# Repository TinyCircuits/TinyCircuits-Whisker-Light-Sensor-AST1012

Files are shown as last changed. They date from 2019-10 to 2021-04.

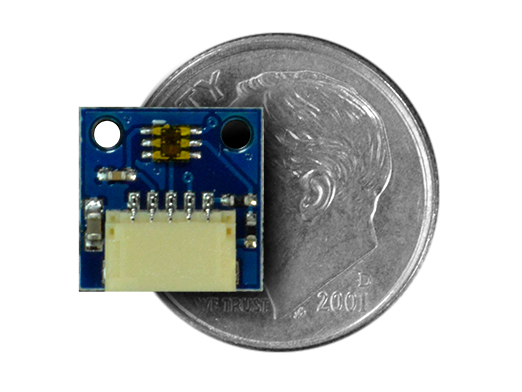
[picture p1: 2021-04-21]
images/AST1012-Product-Photo-03.png

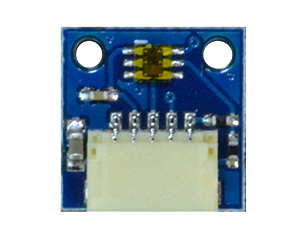
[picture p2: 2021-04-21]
images/AST1012-Learn-Photo-01.png

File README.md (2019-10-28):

# TinyCircuits Wireling Light Sensor
# AST1012 Rev2

The design files are located under design_files/ for the TinyCircuits AST1012 Rev 2 PCB. This is a Wireling board which features the AMS TSL2572 ambient light sensor with built in UV rejection filter and is also capable of operating in IR light environments. Its high sensitivity range enables it to operate even behind dark glass (such as in portable applications like Smartphones).

Format is in Cadsoft Eagle format - Eagle version 6.2 was used for the original design.

For more infomation on this, check out the product page at TinyCircuits.com

# License:

Design by TinyCircuits.
All design files are released under the Creative Commons Attribution Share-Alike 3.0 License, see the following link for details: http://creativecommons.org/licenses/by-sa/3.0

All text above must be included in any redistribution or derived design

This project uses designs and concepts developed as part of the Arduino project and the LilyPad project.  The TinyCircuits design files themselves (schematics, PCB and libraries) are not directly derived from these works' design files and have been created new, however the concepts and basic architecture behind the TinyDuino and TinyLily products are derived and we thank the hard work of the organizations below for their contributions to open-source hardware:
  
Original Arduino Uno Design by Team Arduino

LilyPad Arduino Design by Leah Buechley and Sparkfun Electronics

Please support the open-source hardware community

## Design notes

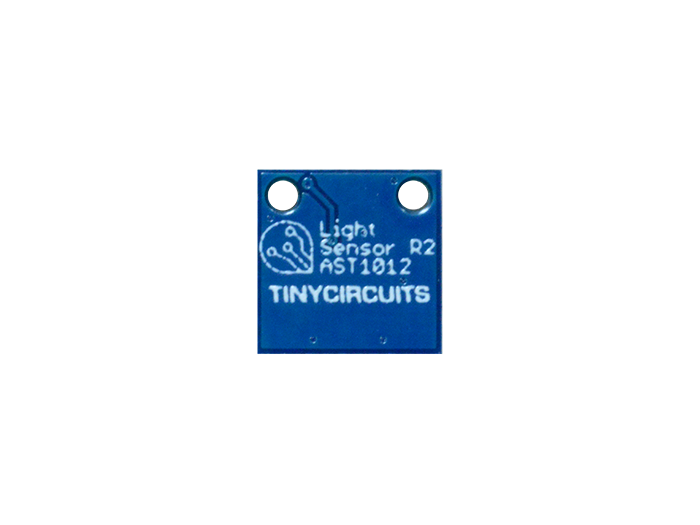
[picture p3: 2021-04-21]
images/AST1012-Product-Photo-02.png

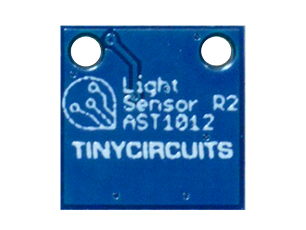
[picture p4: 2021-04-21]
images/AST1012-Learn-Photo-02.png

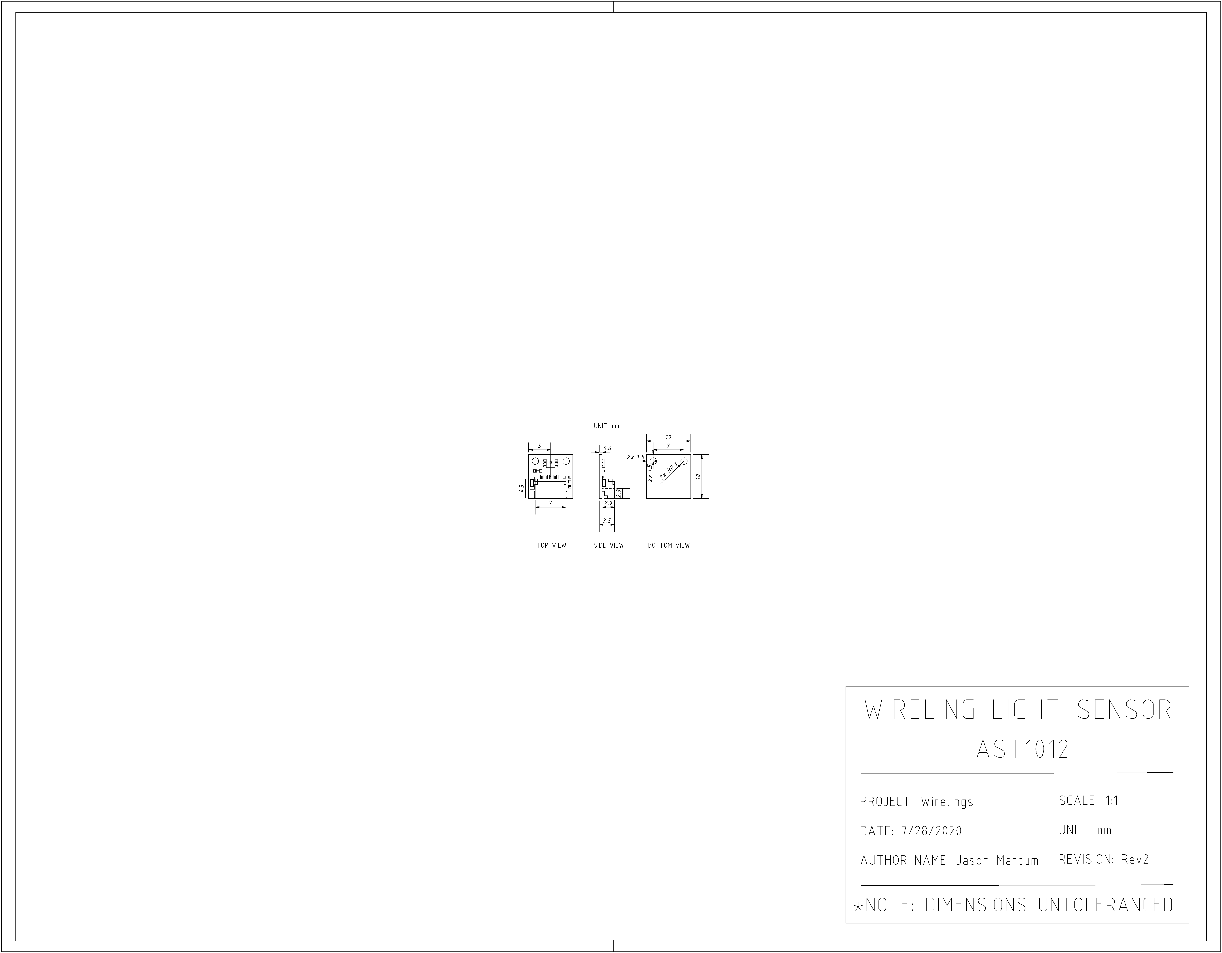
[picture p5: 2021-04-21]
cad/Wireling_LIGHTSENSOR_AST1012_REV2-DETAILED_DRAWING-PNG.png

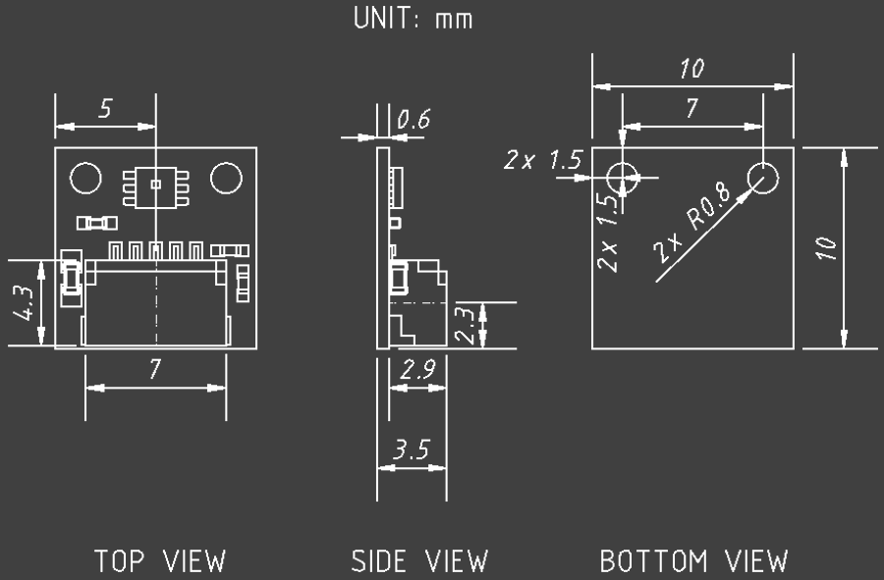
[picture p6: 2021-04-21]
cad/Wireling_LIGHTSENSOR_AST1012_REV2-DETAILED_DRAWING_COMPACT-PNG.png

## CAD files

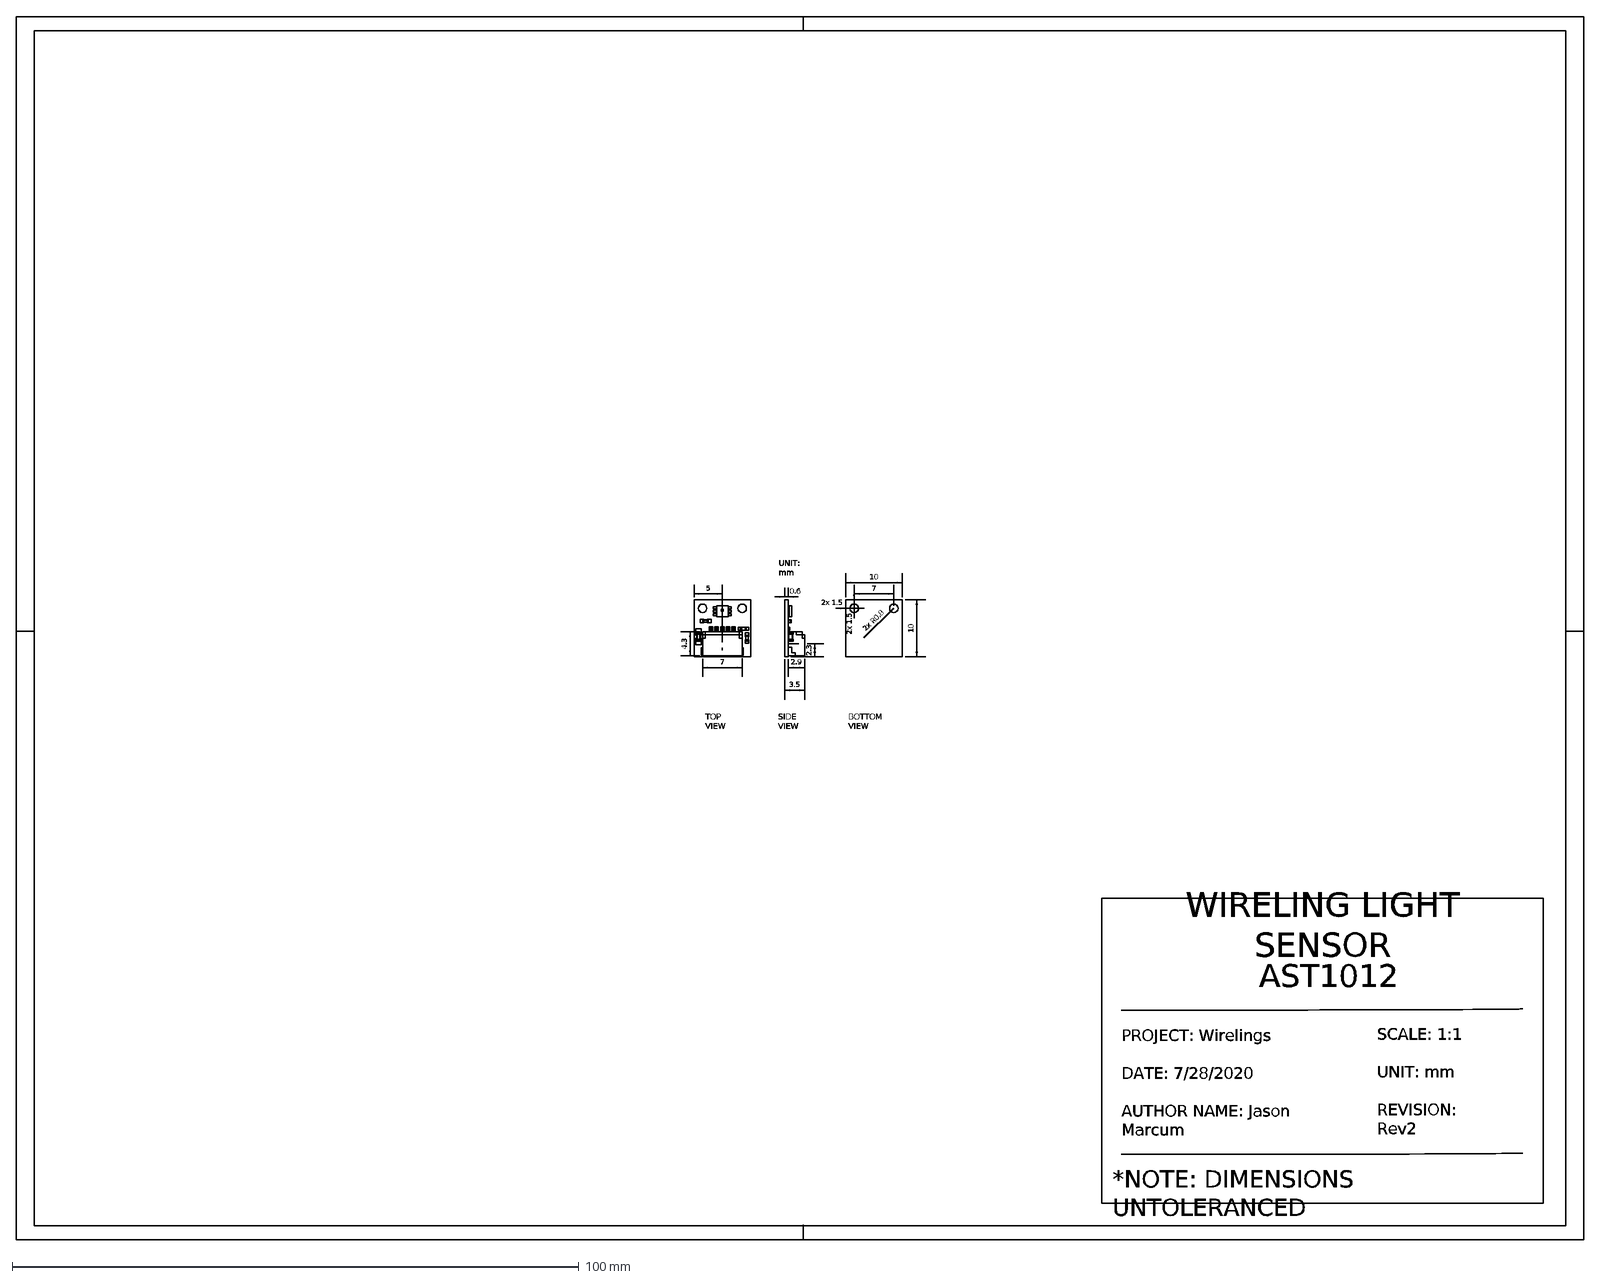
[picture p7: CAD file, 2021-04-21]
cad/Wireling_LIGHTSENSOR_AST1012_REV2-DETAILED_DRAWING-DXF.dxf
*NOTE: DIMENSIONS UNTOLERANCED
UNIT: mm
5
7
4.3
2.3
2.9
3.5
0.6
10
2x 1.5
2x R0.8
TOP VIEW
BOTTOM VIEW
SIDE VIEW
WIRELING LIGHT SENSOR
AST1012
SCALE: 1:1 UNIT: mm REVISION: Rev2
PROJECT: Wirelings DATE: 7/28/2020 AUTHOR NAME: Jason Marcum

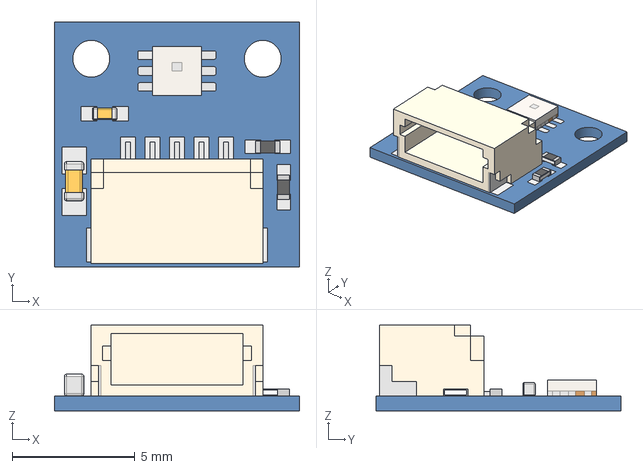
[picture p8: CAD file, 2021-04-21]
cad/Wireling_LIGHTSENSOR_AST1012_REV2-STEP.step
10.0 x 10.0 x 3.50 mm

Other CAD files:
cad/Wireling_LIGHTSENSOR_AST1012_REV2-IGES.iges
cad/Wireling_LIGHTSENSOR_AST1012_REV2-STL.stl

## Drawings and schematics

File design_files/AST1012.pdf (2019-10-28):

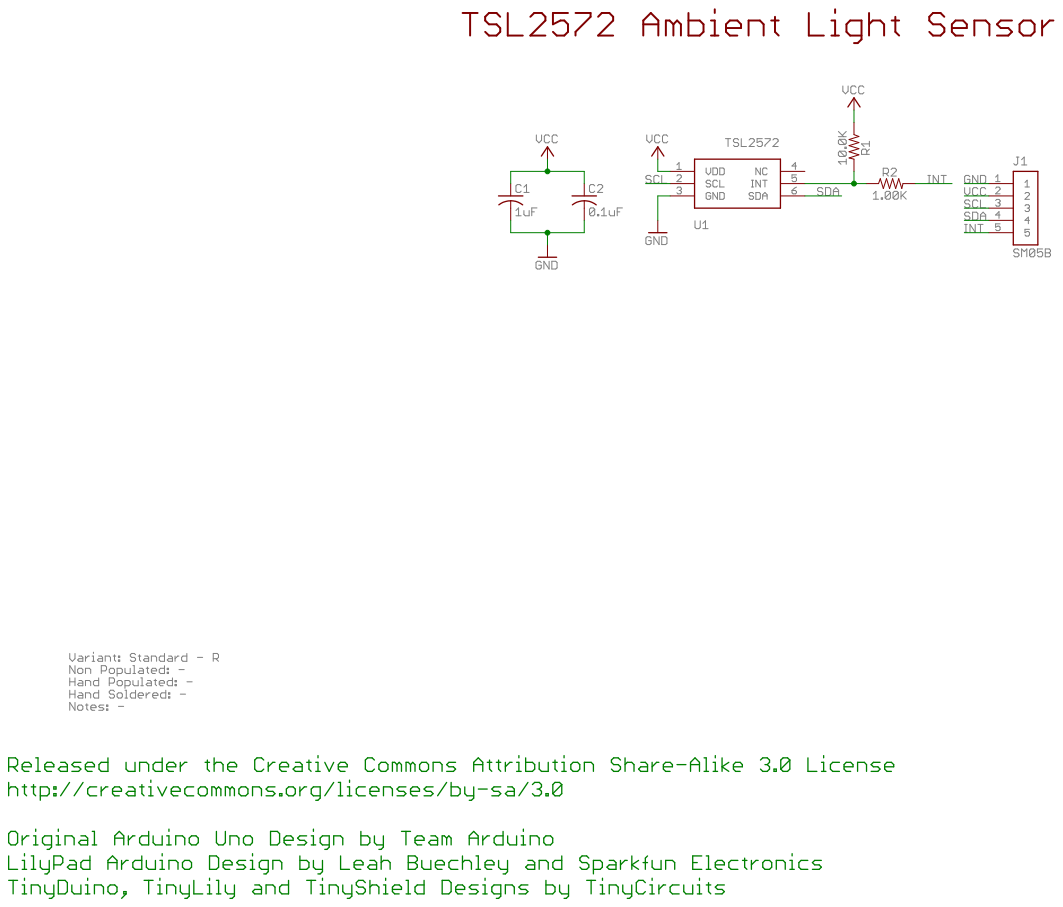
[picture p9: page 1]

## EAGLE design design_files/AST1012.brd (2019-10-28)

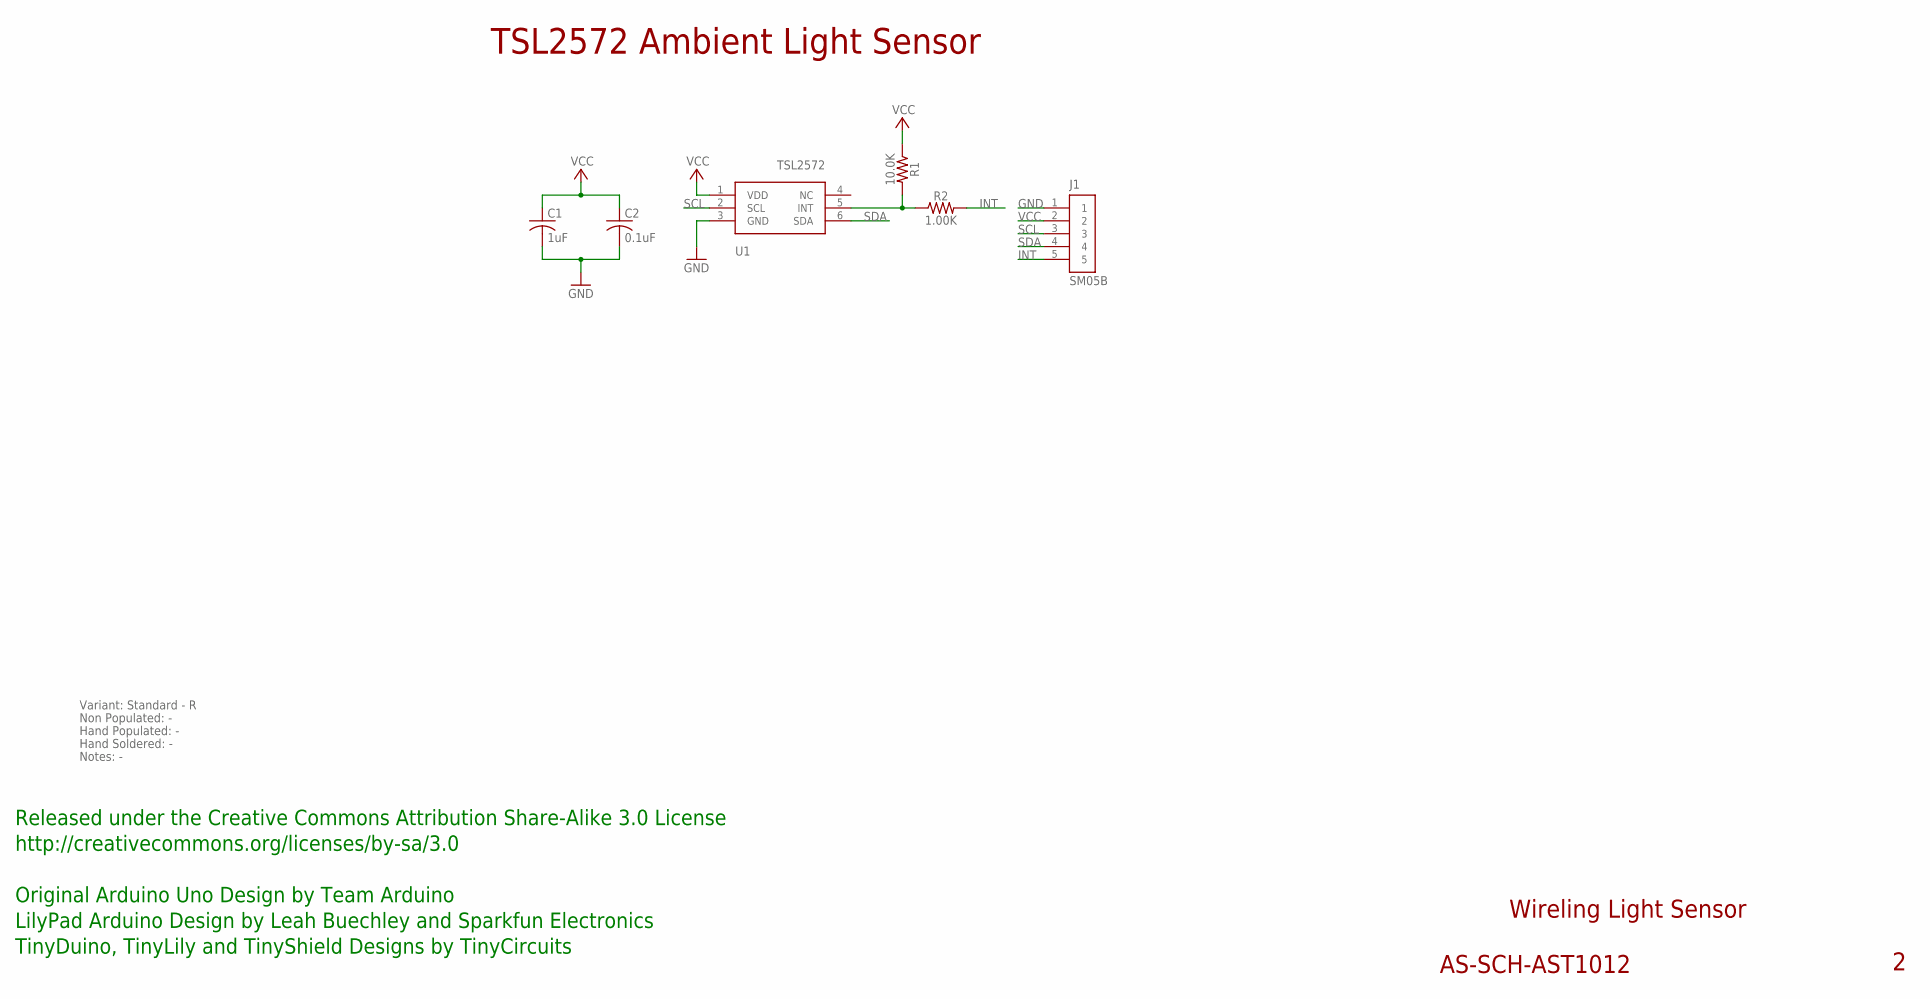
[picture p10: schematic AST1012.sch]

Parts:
C1: 1uF; C0603; PARTNO AS-ITM-00410
C2: 0.1uF; C0402
J1: SM05B; JST_SH_5X1_EDGE
R1: 10.0K; 0402; PARTNO AS-ITM-00032
R2: 1.00K; 0402; PARTNO AS-ITM-00003
U1: TSL2572; PARTNO AS-ITM-00116

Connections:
GND: C1.2, C2.2, J1.1, U1.3 (GND)
GPIO1: R1.2, R2.1, U1.5 (INT)
INT: J1.5, R2.2
SCL: J1.3, U1.2 (SCL)
SDA: J1.4, U1.6 (SDA)
VCC: C1.1, C2.1, J1.2, R1.1, U1.1 (VDD)

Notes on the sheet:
Wireling Light Sensor
AS-SCH-AST1012
TSL2572 Ambient Light Sensor
Released under the Creative Commons Attribution Share-Alike 3.0 License
http://creativecommons.org/licenses/by-sa/3.0
Original Arduino Uno Design by Team Arduino
TinyDuino, TinyLily and TinyShield Designs by TinyCircuits
LilyPad Arduino Design by Leah Buechley and Sparkfun Electronics
Variant: Standard - R
Non Populated: -
Hand Populated: -
Hand Soldered: -
Notes: -

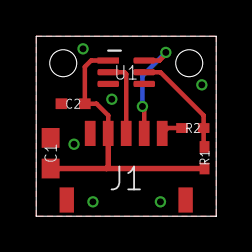
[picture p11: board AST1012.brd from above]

Board: 2 copper layers, 10.0 x 10.0 mm, 7 parts (0 on the bottom side), 6 nets.

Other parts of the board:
U$1: DOCFIELD-TINYCIRCUITS-PCB

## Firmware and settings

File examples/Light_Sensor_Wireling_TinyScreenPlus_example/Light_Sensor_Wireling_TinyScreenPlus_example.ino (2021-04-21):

/*************************************************************************
 * TSL2572 Ambient Light Sensor Wireling Tutorial:
 * This program will print the lux value read from the sensor to both the 
 * TinyScreen+ if used, and the Serial Monitor
 * 
 * Hardware by: TinyCircuits
 * Code by: Laveréna Wienclaw for TinyCircuits
 *
 * Initiated: 11/29/2017 
 * Updated: 04/21/2021
 ************************************************************************/

#include <Wire.h>         // For I2C communication with sensor
#include <TinyScreen.h>   // For interfacing with the TinyScreen+
#include <Wireling.h>     // For interfacing with Wirelings

// TinyScreen+ variables
TinyScreen display = TinyScreen(TinyScreenPlus);
int background = TS_8b_Black;

// Communication address with the sensor
#define TSL2572_I2CADDR     0x39

// Sets the gain
#define   GAIN_1X 0
#define   GAIN_8X 1
#define  GAIN_16X 2
#define GAIN_120X 3

//only use this with 1x and 8x gain settings
#define GAIN_DIVIDE_6 false

// Global variable for gain value used to Read the sensor
int gain_val = 0;

// Make Serial Monitor compatible for all TinyCircuits processors
#if defined(ARDUINO_ARCH_AVR)
  #define SerialMonitorInterface Serial
#elif defined(ARDUINO_ARCH_SAMD)
  #define SerialMonitorInterface SerialUSB
#endif

void setup() {
  SerialMonitorInterface.begin(9600);
  Wire.begin();

  // Initialize Wireling
  Wireling.begin();
  Wireling.selectPort(0); // Port #'s correspond to backside of the Adapter TinyShield

  // Setup and style for TinyScreen+
  display.begin();
  display.setFlip(true);
  display.setBrightness(15);
  display.setFont(thinPixel7_10ptFontInfo);
  display.fontColor(TS_8b_White, background);

//***************************************
// SETTINGS & ADJUSTMENTS 
//***************************************
//  TSL2572Init(GAIN_1X);
//  TSL2572Init(GAIN_8X);
  TSL2572Init(GAIN_16X);
  //TSL2572Init(GAIN_120X);
}

void loop() {
  float AmbientLightLux = Tsl2572ReadAmbientLight();

  // Print lux value to Serial Monitor
  SerialMonitorInterface.print("Lux: ");
  SerialMonitorInterface.println(AmbientLightLux);

  // This will make the screen look a little unsteady but is needed in order
  // to clear old values 
  display.clearScreen();
  printScreen(AmbientLightLux); // Print lux to TinyScreen
  delay(500);
}

// Prints the lux values to the TinyScreen
void printScreen(float luxValue){
  // This will make the screen look a little unsteady but is needed in order
  // to clear old values 
  display.clearScreen();
  
  display.fontColor(TS_8b_White, background);
  display.setCursor(0, 0);
  display.print("TSL2572 Values:");

  display.fontColor(TS_8b_Yellow, background);
  display.setCursor(0, 12);
  display.print("Lux = ");
  display.print(luxValue);
}

// Used to interface with the sensor by writing to its registers directly 
void Tsl2572RegisterWrite(byte regAddr, byte regData) {
  Wire.beginTransmission(TSL2572_I2CADDR);
  Wire.write(0x80 | regAddr);
  Wire.write(regData);
  Wire.endTransmission();
}

// Initializes the light sensor to be ready for output
void TSL2572Init(uint8_t gain) {
  Tsl2572RegisterWrite( 0x0F, gain );//set gain
  Tsl2572RegisterWrite( 0x01, 0xED );//51.87 ms
  Tsl2572RegisterWrite( 0x00, 0x03 );//turn on
  if (GAIN_DIVIDE_6)
    Tsl2572RegisterWrite( 0x0D, 0x04 );//scale gain by 0.16
  if (gain == GAIN_1X)gain_val = 1;
  else if (gain == GAIN_8X)gain_val = 8;
  else if (gain == GAIN_16X)gain_val = 16;
  else if (gain == GAIN_120X)gain_val = 120;
}

// Read the lux value from the light sensor so we can print it out
float Tsl2572ReadAmbientLight() {
  uint8_t data[4];
  int c0, c1;
  float lux1, lux2, cpl;

  Wire.beginTransmission(TSL2572_I2CADDR);
  Wire.write(0xA0 | 0x14);
  Wire.endTransmission();
  Wire.requestFrom(TSL2572_I2CADDR, 4);
  for (uint8_t i = 0; i < 4; i++)
    data[i] = Wire.read();

  c0 = data[1] << 8 | data[0];
  c1 = data[3] << 8 | data[2];

  //see TSL2572 datasheet: https://www.mouser.com/ds/2/588/TSL2672_Datasheet_EN_v1-255424.pdf
  cpl = 51.87 * (float)gain_val / 60.0;
  if (GAIN_DIVIDE_6) cpl /= 6.0;
  lux1 = ((float)c0 - (1.87 * (float)c1)) / cpl;
  lux2 = ((0.63 * (float)c0) - (float)c1) / cpl;
  cpl = max(lux1, lux2);
  return max(cpl, 0.0);
}

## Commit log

2019-09-26 images and code fix
    [Light_Whisker_example.ino]
2019-10-28 name change
    [AST1012.brd, AST1012.sch]
2019-11-22 power pin
2020-08-14 Add CAD data
    [Wireling_LIGHTSENSOR_AST1012_REV2-DETAILED_DRAWING-DXF.dxf, Wireling_LIGHTSENSOR_AST1012_REV2-IGES.iges, Wireling_LIGHTSENSOR_AST1012_REV2-STEP.step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]
